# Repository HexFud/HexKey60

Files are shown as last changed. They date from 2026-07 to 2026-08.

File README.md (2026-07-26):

## HexKey60

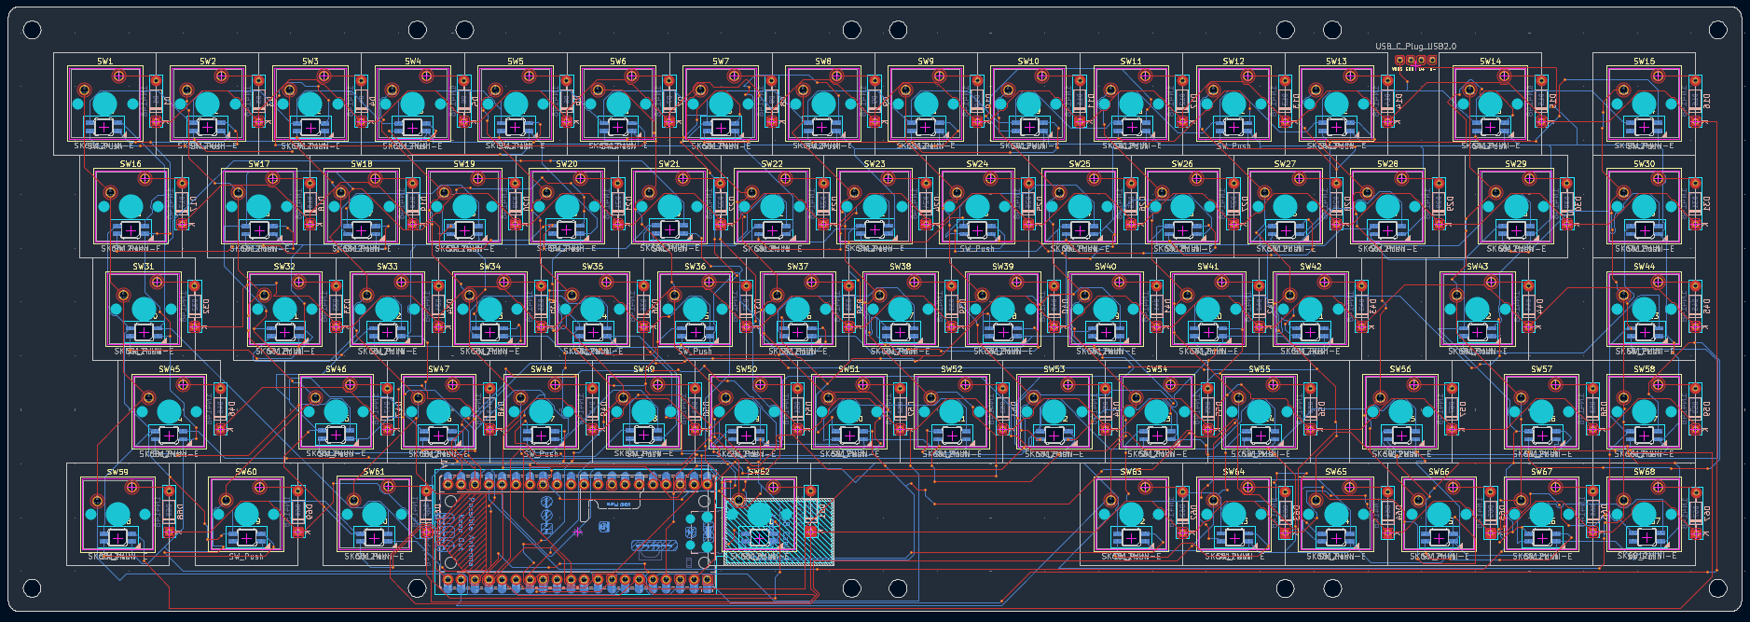
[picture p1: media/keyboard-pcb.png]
HexKey60


Just a custom mechanical keyboard project designed by me

## Specs

- **Layout:** 68 keys, 15 columns x 5 rows matrix, ANSI 65% (up arrow between right Shift and Delete, left/down/right arrows on the bottom row, Fn next to AltGr)
- **Microcontroller:** Raspberry Pi Pico (RP2040), mounted under the spacebar
- **LEDs:** SK6812MINI-E, one per key, same color across the whole board
- **Matrix diodes:** 1N4148, one per switch
- **USB:** routed from the microcontroller (under the spacebar) up to the connector at the top of the case via a Treedix USB-C breakout

## Why the Pico and not something smaller

Originally I was going for something more compact (Orpheus Pico, then XIAO RP2040, then RP2040-Zero) because the standard Pico seemed too bulky to fit between the switches. That problem went away once I moved the microcontroller under the spacebar, where there's way more free space, at that point the regular Pico made more sense, i had space to place it and it has enough pins to fit evry component.

## Matrix

- Rows: GPIO0-GPIO4
- Columns: GPIO5-GPIO19
- Every switch has its own diode to prevent ghosting

## LEDs

Driven via PIO on GPIO21.

LED power comes straight from VBUS (5V), not from the Pico's 3.3V regulator, so the current spikes from 68 LEDs at once don't stress it. Max brightness needs to stay capped in firmware.

## USB

The Pico sits under the spacebar, away from the case edge where the connector needs to come out. D+/D- are hand-wired to test points TP2/TP3 on the back of the Pico (not routed through the PCB), going to a Treedix USB-C breakout mounted in the case. CC1/CC2 on the breakout already have pull-down resistors built in, so they're left unconnected.

## Plate

The plate and the case are fully 3d printed

## Firmware

Live control from a PC over Raw HID (`tastiera68_controller.py`, requires `pip install hidapi`):
- change LED color on the fly (persistent, saved to the Pico's emulated EEPROM)
- remap any key without reflashing (also persistent, saved to a dedicated EEPROM area)

## Building the firmware

### 1. Get QMK

If you don't already have a QMK checkout:

```
git clone https://github.com/qmk/qmk_firmware.git
cd qmk_firmware
```

Follow QMK's own setup guide once (https://docs.qmk.fm/#/newbs_getting_started)
to install the build environment (Python, the ARM toolchain, etc.) if you
haven't done that before — it's a one-time setup per PC.

### 2. Drop this keyboard into the QMK tree

Copy the whole `HexKey60` folder into `qmk_firmware/keyboards/`, so you end
up with:

```
qmk_firmware/
  keyboards/
    HexKey60/
      info.json
      keymaps/
        default/
          keymap.c
          rules.mk
```

### 3. Compile

From the `qmk_firmware` root:

```
qmk compile -kb HexKey60 -km default
```

If everything is set up correctly this produces a file called something
like `HexKey60_default.uf2` in the `qmk_firmware` root folder.

If the build fails on the EEPROM driver lines in `rules.mk`
(`EEPROM_DRIVER` / `WEAR_LEVELING_DRIVER`), check QMK's current docs for the
exact driver name used for RP2040 in your checkout's version — the name has
changed between QMK releases.

### 4. Put the Pico into bootloader mode

The RP2040 shows up as a USB mass-storage drive (`RPI-RP2`) when it's ready
to receive new firmware:

1. Unplug the keyboard.
2. Hold down the **BOOTSEL** button on the Pico (the small white button on
   the board itself).
3. While still holding it, plug the USB cable back in.
4. Let go of the button — a drive called `RPI-RP2` should appear on your
   computer, the same way a USB flash drive would.

### 5. Flash

Just drag and drop the `.uf2` file you built in step 3 onto the `RPI-RP2`
drive. The Pico reboots on its own as soon as the copy finishes, and the
keyboard should now be running your firmware.

If `qmk flash` is set up on your system instead, this also works and does
the copy for you:

```
qmk flash -kb HexKey60 -km default
```

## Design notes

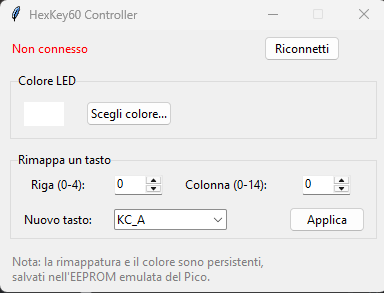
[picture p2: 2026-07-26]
media/firmware.png

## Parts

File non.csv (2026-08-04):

Item | Quantity | Notes | Estimated Price (EUR)
Akko CS 36gf Tactile Keyboard Switches - Lavender Purple, Plate Mounted, Compatible for MX Mechanical Keyboard | 1 | Matrix switches (usually sold in boxes of 45, a 65/75% layout requires 2 boxes) | 35.00
1N4148 Diodes | 68 | One per switch, matrix diode | 3.00
Orpheus Pico | 1 | Microcontroller | 7.50
EG Everglide Panda Stabilizer Gold Plated Plate Mounted Black White Stabilizer (EG Panda for 104) | 1 | Stabilizers for long keys | 20.00
SK6812 MINI-E LEDs | 68 | One per key, wired as 7 parallel groups on GPIO21 (single static color) | 12.50
PCB (see the production folder) | 1 | Custom printed circuit board | 25.00
AKKO Black & Gold ISO Nordic Keycap Set (76-Key) | 1 | Keycap set | 55.00
Adafruit USB Type C Breakout Board - Downstream Connection | 1 | USB-C connector breakout | 6.00
Case | 1 | 3D Printed | 20.00
Plate | 1 | 3D Printed | 7.50

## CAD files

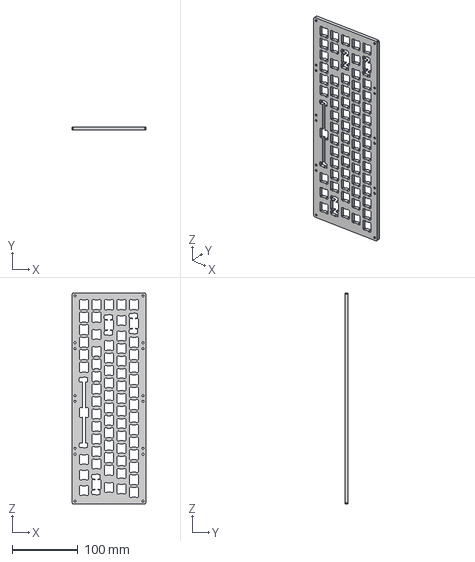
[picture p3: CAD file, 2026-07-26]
CAD/plate.step
112.3 x 5.00 x 321.8 mm

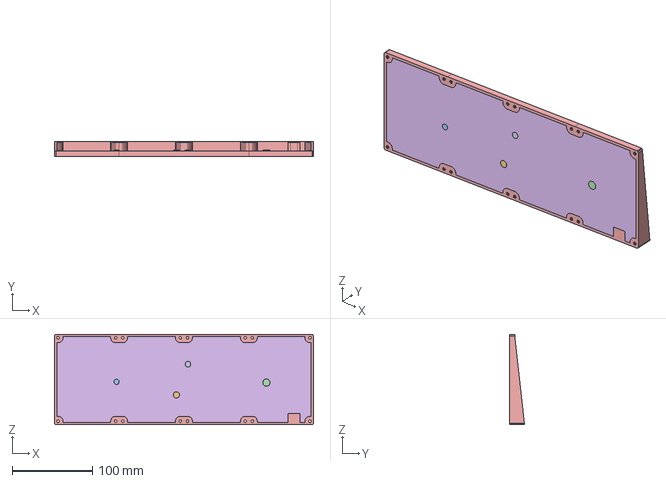
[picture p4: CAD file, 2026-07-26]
CAD/case.step
321.8 x 18.8 x 112.3 mm

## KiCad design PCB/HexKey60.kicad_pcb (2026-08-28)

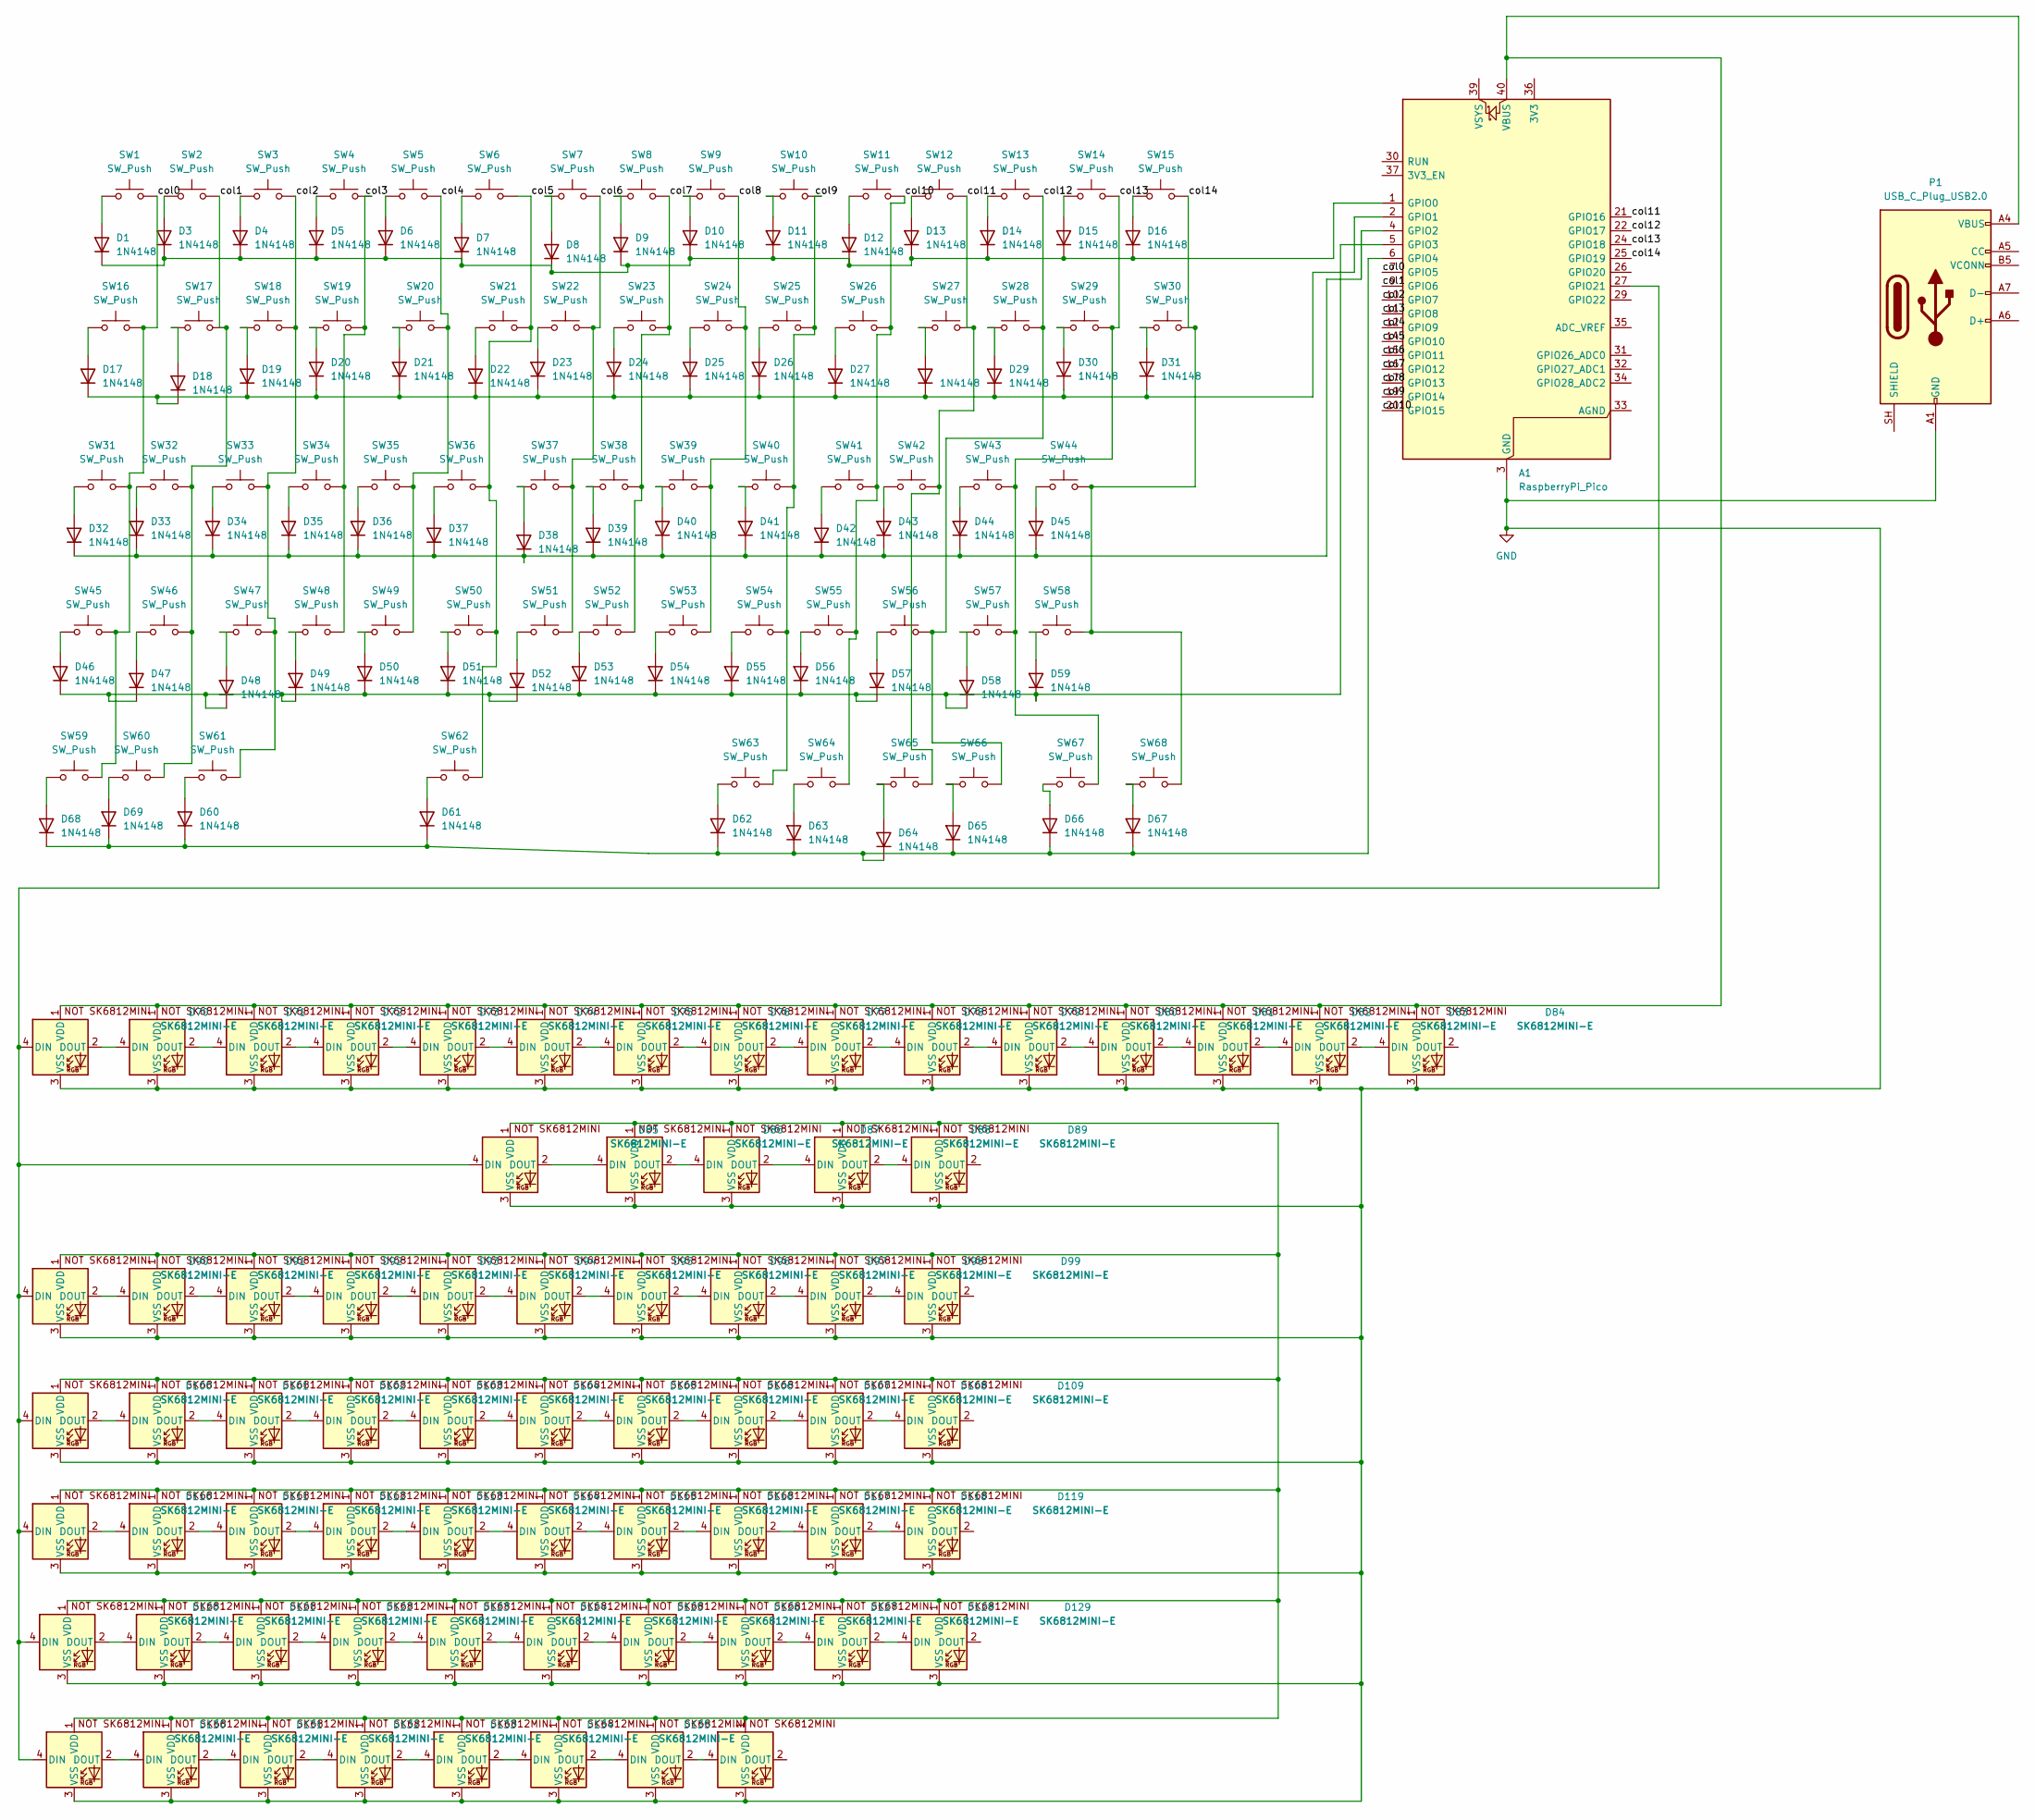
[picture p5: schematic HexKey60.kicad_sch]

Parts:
A1: RaspberryPi_Pico; RaspberryPi_Pico_Common_Unspecified
D1, D3, D4, D5, D6, D7, D8, D9, D10, D11, D12, D13, D14, D15, D16, D17, D18, D19, D20, D21, D22, D23, D24, D25, D26, D27, D28, D29, D30, D31, D32, D33, D34, D35, D36, D37, D38, D39, D40, D41, D42, D43, D44, D45, D46, D47, D48, D49, D50, D51, D52, D53, D54, D55, D56, D57, D58, D59, D60, D61, D62, D63, D64, D65, D66, D67, D68, D69: 1N4148; D_DO-35_SOD27_P7.62mm_Horizontal
D70, D71, D72, D73, D74, D75, D76, D77, D78, D79, D80, D81, D82, D83, D84, D85, D86, D87, D88, D89, D90, D91, D92, D93, D94, D95, D96, D97, D98, D99, D100, D101, D102, D103, D104, D105, D106, D107, D108, D109, D110, D111, D112, D113, D114, D115, D116, D117, D118, D119, D120, D121, D122, D123, D124, D125, D126, D127, D128, D129, D130, D131, D132, D133, D134, D135, D136, D137: SK6812MINI-E; SK6812MINI-E_fixed
P1: USB_C_Plug_USB2.0; usbc board
SW1, SW2, SW3, SW4, SW5, SW6, SW7, SW8, SW9, SW10, SW11, SW12, SW13, SW14, SW15, SW16, SW17, SW18, SW19, SW20, SW21, SW22, SW23, SW24, SW25, SW26, SW27, SW28, SW29, SW30, SW31, SW32, SW33, SW34, SW35, SW36, SW37, SW38, SW39, SW40, SW41, SW42, SW43, SW44, SW45, SW46, SW47, SW48, SW49, SW50, SW51, SW52, SW53, SW54, SW55, SW56, SW57, SW58, SW59, SW60, SW61, SW62, SW63, SW64, SW65, SW66, SW67, SW68: SW_Push; SW_Cherry_MX_1.00u_PCB

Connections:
/<NO NET>: A1.7 (GPIO5), SW1.2, SW16.2, SW31.2, SW45.2, SW59.2
/col1: A1.9 (GPIO6), SW2.2, SW17.2, SW32.2, SW46.2, SW60.2
/col2: A1.10 (GPIO7), SW3.2, SW18.2, SW33.2, SW47.2, SW61.2
/col3: A1.11 (GPIO8), SW4.2, SW19.2, SW34.2, SW48.2
/col4: A1.12 (GPIO9), SW5.2, SW20.2, SW35.2, SW49.2
/col5: A1.14 (GPIO10), SW6.2, SW21.2, SW36.2, SW50.2, SW62.2
/col6: A1.15 (GPIO11), SW7.2, SW22.2, SW37.2, SW51.2
/col7: A1.16 (GPIO12), SW8.2, SW23.2, SW38.2, SW52.2
/col8: A1.17 (GPIO13), SW9.2, SW24.2, SW39.2, SW53.2
/col9: A1.19 (GPIO14), SW10.2, SW25.2, SW40.2, SW54.2, SW63.2
/col10: A1.20 (GPIO15), SW11.2, SW26.2, SW41.2, SW55.2, SW64.2
/col11: A1.21 (GPIO16), SW12.2, SW27.2, SW42.2, SW65.2
/col12: A1.22 (GPIO17), SW13.2, SW28.2, SW56.2, SW66.2
/col13: A1.24 (GPIO18), SW14.2, SW29.2, SW43.2, SW57.2, SW67.2
/col14: A1.25 (GPIO19), SW15.2, SW30.2, SW44.2, SW58.2, SW68.2
GND: A1.3 (GND), A1.8 (GND), A1.13 (GND), A1.18 (GND), A1.23 (GND), A1.28 (GND), A1.38 (GND), D70.3 (VSS), D71.3 (VSS), D72.3 (VSS), D73.3 (VSS), D74.3 (VSS), D75.3 (VSS), D76.3 (VSS), D77.3 (VSS), D78.3 (VSS), D79.3 (VSS), D80.3 (VSS), D81.3 (VSS), D82.3 (VSS), D83.3 (VSS), D84.3 (VSS), D85.3 (VSS), D86.3 (VSS), D87.3 (VSS), D88.3 (VSS), D89.3 (VSS), D90.3 (VSS), D91.3 (VSS), D92.3 (VSS), D93.3 (VSS), D94.3 (VSS), D95.3 (VSS), D96.3 (VSS), D97.3 (VSS), D98.3 (VSS), D99.3 (VSS), D100.3 (VSS), D101.3 (VSS), D102.3 (VSS), D103.3 (VSS), D104.3 (VSS), D105.3 (VSS), D106.3 (VSS), D107.3 (VSS), D108.3 (VSS), D109.3 (VSS), D110.3 (VSS), D111.3 (VSS), D112.3 (VSS), D113.3 (VSS), D114.3 (VSS), D115.3 (VSS), D116.3 (VSS), D117.3 (VSS), D118.3 (VSS), D119.3 (VSS), D120.3 (VSS), D121.3 (VSS), D122.3 (VSS), D123.3 (VSS), D124.3 (VSS), D125.3 (VSS), D126.3 (VSS), D127.3 (VSS), D128.3 (VSS), D129.3 (VSS), D130.3 (VSS), D131.3 (VSS), D132.3 (VSS), D133.3 (VSS), D134.3 (VSS), D135.3 (VSS), D136.3 (VSS), D137.3 (VSS), P1.A1 (GND), P1.A12 (GND), P1.B1 (GND), P1.B12 (GND)
unnamed: A1.1 (GPIO0), D1.1 (K), D3.1 (K), D4.1 (K), D5.1 (K), D6.1 (K), D7.1 (K), D8.1 (K), D9.1 (K), D10.1 (K), D11.1 (K), D12.1 (K), D13.1 (K), D14.1 (K), D15.1 (K), D16.1 (K)
unnamed: A1.2 (GPIO1), D17.1 (K), D18.1 (K), D19.1 (K), D20.1 (K), D21.1 (K), D22.1 (K), D23.1 (K), D24.1 (K), D25.1 (K), D26.1 (K), D27.1 (K), D28.1 (K), D29.1 (K), D30.1 (K), D31.1 (K)
unnamed: A1.4 (GPIO2), D32.1 (K), D33.1 (K), D34.1 (K), D35.1 (K), D36.1 (K), D37.1 (K), D38.1 (K), D39.1 (K), D40.1 (K), D41.1 (K), D42.1 (K), D43.1 (K), D44.1 (K), D45.1 (K)
unnamed: A1.5 (GPIO3), D46.1 (K), D47.1 (K), D48.1 (K), D49.1 (K), D50.1 (K), D51.1 (K), D52.1 (K), D53.1 (K), D54.1 (K), D55.1 (K), D56.1 (K), D57.1 (K), D58.1 (K), D59.1 (K)
unnamed: A1.6 (GPIO4), D60.1 (K), D61.1 (K), D62.1 (K), D63.1 (K), D64.1 (K), D65.1 (K), D66.1 (K), D67.1 (K), D68.1 (K), D69.1 (K)
unnamed: A1.27 (GPIO21), D70.4 (DIN), D85.4 (DIN), D90.4 (DIN), D100.4 (DIN), D110.4 (DIN), D120.4 (DIN), D130.4 (DIN)
unnamed: A1.40 (VBUS), D70.1 (VDD), D71.1 (VDD), D72.1 (VDD), D73.1 (VDD), D74.1 (VDD), D75.1 (VDD), D76.1 (VDD), D77.1 (VDD), D78.1 (VDD), D79.1 (VDD), D80.1 (VDD), D81.1 (VDD), D82.1 (VDD), D83.1 (VDD), D84.1 (VDD), P1.A4 (VBUS), P1.A9 (VBUS), P1.B4 (VBUS), P1.B9 (VBUS)
unnamed: D1.2 (A), SW1.1
unnamed: D3.2 (A), SW2.1
unnamed: D4.2 (A), SW3.1
unnamed: D5.2 (A), SW4.1
unnamed: D6.2 (A), SW5.1
unnamed: D7.2 (A), SW6.1
unnamed: D8.2 (A), SW7.1
unnamed: D9.2 (A), SW8.1
unnamed: D10.2 (A), SW9.1
unnamed: D11.2 (A), SW10.1
unnamed: D12.2 (A), SW11.1
unnamed: D13.2 (A), SW12.1
unnamed: D14.2 (A), SW13.1
unnamed: D15.2 (A), SW14.1
unnamed: D16.2 (A), SW15.1
unnamed: D17.2 (A), SW16.1
unnamed: D18.2 (A), SW17.1
unnamed: D19.2 (A), SW18.1
unnamed: D20.2 (A), SW19.1
unnamed: D21.2 (A), SW20.1
unnamed: D22.2 (A), SW21.1
unnamed: D23.2 (A), SW22.1
unnamed: D24.2 (A), SW23.1
unnamed: D25.2 (A), SW24.1
unnamed: D26.2 (A), SW25.1
unnamed: D27.2 (A), SW26.1
unnamed: D28.2 (A), SW27.1
unnamed: D29.2 (A), SW28.1
unnamed: D30.2 (A), SW29.1
unnamed: D31.2 (A), SW30.1
unnamed: D32.2 (A), SW31.1
unnamed: D33.2 (A), SW32.1
unnamed: D34.2 (A), SW33.1
unnamed: D35.2 (A), SW34.1
unnamed: D36.2 (A), SW35.1
unnamed: D37.2 (A), SW36.1
unnamed: D38.2 (A), SW37.1
unnamed: D39.2 (A), SW38.1
unnamed: D40.2 (A), SW39.1
unnamed: D41.2 (A), SW40.1
unnamed: D42.2 (A), SW41.1
unnamed: D43.2 (A), SW42.1
unnamed: D44.2 (A), SW43.1
unnamed: D45.2 (A), SW44.1
unnamed: D46.2 (A), SW45.1
unnamed: D47.2 (A), SW46.1
unnamed: D48.2 (A), SW47.1
unnamed: D49.2 (A), SW48.1
unnamed: D50.2 (A), SW49.1
unnamed: D51.2 (A), SW50.1
unnamed: D52.2 (A), SW51.1
unnamed: D53.2 (A), SW52.1
unnamed: D54.2 (A), SW53.1
unnamed: D55.2 (A), SW54.1
unnamed: D56.2 (A), SW55.1
unnamed: D57.2 (A), SW56.1
unnamed: D58.2 (A), SW57.1
unnamed: D59.2 (A), SW58.1
unnamed: D60.2 (A), SW61.1
unnamed: D61.2 (A), SW62.1
unnamed: D62.2 (A), SW63.1
unnamed: D63.2 (A), SW64.1
unnamed: D64.2 (A), SW65.1
unnamed: D65.2 (A), SW66.1
unnamed: D66.2 (A), SW67.1
unnamed: D67.2 (A), SW68.1
unnamed: D68.2 (A), SW59.1
unnamed: D69.2 (A), SW60.1
unnamed: D70.2 (DOUT), D71.4 (DIN)
unnamed: D71.2 (DOUT), D72.4 (DIN)
unnamed: D72.2 (DOUT), D73.4 (DIN)
unnamed: D73.2 (DOUT), D74.4 (DIN)
unnamed: D74.2 (DOUT), D75.4 (DIN)
unnamed: D75.2 (DOUT), D76.4 (DIN)
unnamed: D76.2 (DOUT), D77.4 (DIN)
unnamed: D77.2 (DOUT), D78.4 (DIN)
unnamed: D78.2 (DOUT), D79.4 (DIN)
unnamed: D79.2 (DOUT), D80.4 (DIN)
unnamed: D80.2 (DOUT), D81.4 (DIN)
unnamed: D81.2 (DOUT), D82.4 (DIN)
unnamed: D82.2 (DOUT), D83.4 (DIN)
unnamed: D83.2 (DOUT), D84.4 (DIN)
unnamed: D85.2 (DOUT), D86.4 (DIN)
unnamed: D86.2 (DOUT), D87.4 (DIN)
unnamed: D87.2 (DOUT), D88.4 (DIN)
unnamed: D88.2 (DOUT), D89.4 (DIN)
unnamed: D90.2 (DOUT), D91.4 (DIN)
unnamed: D91.2 (DOUT), D92.4 (DIN)
unnamed: D92.2 (DOUT), D93.4 (DIN)
unnamed: D93.2 (DOUT), D94.4 (DIN)
unnamed: D94.2 (DOUT), D95.4 (DIN)
unnamed: D95.2 (DOUT), D96.4 (DIN)
unnamed: D96.2 (DOUT), D97.4 (DIN)
unnamed: D97.2 (DOUT), D98.4 (DIN)
unnamed: D98.2 (DOUT), D99.4 (DIN)
unnamed: D100.2 (DOUT), D101.4 (DIN)
unnamed: D85.1 (VDD), D86.1 (VDD), D87.1 (VDD), D88.1 (VDD), D89.1 (VDD), D90.1 (VDD), D91.1 (VDD), D92.1 (VDD), D93.1 (VDD), D94.1 (VDD), D95.1 (VDD), D96.1 (VDD), D97.1 (VDD), D98.1 (VDD), D99.1 (VDD), D100.1 (VDD), D101.1 (VDD), D102.1 (VDD), D103.1 (VDD), D104.1 (VDD), D105.1 (VDD), D106.1 (VDD), D107.1 (VDD), D108.1 (VDD), D109.1 (VDD), D110.1 (VDD), D111.1 (VDD), D112.1 (VDD), D113.1 (VDD), D114.1 (VDD), D115.1 (VDD), D116.1 (VDD), D117.1 (VDD), D118.1 (VDD), D119.1 (VDD), D120.1 (VDD), D121.1 (VDD), D122.1 (VDD), D123.1 (VDD), D124.1 (VDD), D125.1 (VDD), D126.1 (VDD), D127.1 (VDD), D128.1 (VDD), D129.1 (VDD), D130.1 (VDD), D131.1 (VDD), D132.1 (VDD), D133.1 (VDD), D134.1 (VDD), D135.1 (VDD), D136.1 (VDD), D137.1 (VDD)
unnamed: D101.2 (DOUT), D102.4 (DIN)
unnamed: D102.2 (DOUT), D103.4 (DIN)
unnamed: D103.2 (DOUT), D104.4 (DIN)
unnamed: D104.2 (DOUT), D105.4 (DIN)
unnamed: D105.2 (DOUT), D106.4 (DIN)
unnamed: D106.2 (DOUT), D107.4 (DIN)
unnamed: D107.2 (DOUT), D108.4 (DIN)
unnamed: D108.2 (DOUT), D109.4 (DIN)
unnamed: D110.2 (DOUT), D111.4 (DIN)
unnamed: D111.2 (DOUT), D112.4 (DIN)
unnamed: D112.2 (DOUT), D113.4 (DIN)
unnamed: D113.2 (DOUT), D114.4 (DIN)
unnamed: D114.2 (DOUT), D115.4 (DIN)
unnamed: D115.2 (DOUT), D116.4 (DIN)
unnamed: D116.2 (DOUT), D117.4 (DIN)
unnamed: D117.2 (DOUT), D118.4 (DIN)
unnamed: D118.2 (DOUT), D119.4 (DIN)
unnamed: D120.2 (DOUT), D121.4 (DIN)
unnamed: D121.2 (DOUT), D122.4 (DIN)
unnamed: D122.2 (DOUT), D123.4 (DIN)
unnamed: D123.2 (DOUT), D124.4 (DIN)
unnamed: D124.2 (DOUT), D125.4 (DIN)
unnamed: D125.2 (DOUT), D126.4 (DIN)
unnamed: D126.2 (DOUT), D127.4 (DIN)
unnamed: D127.2 (DOUT), D128.4 (DIN)
unnamed: D128.2 (DOUT), D129.4 (DIN)
unnamed: D130.2 (DOUT), D131.4 (DIN)
unnamed: D131.2 (DOUT), D132.4 (DIN)
unnamed: D132.2 (DOUT), D133.4 (DIN)
unnamed: D133.2 (DOUT), D134.4 (DIN)
unnamed: D134.2 (DOUT), D135.4 (DIN)
unnamed: D135.2 (DOUT), D136.4 (DIN)
unnamed: D136.2 (DOUT), D137.4 (DIN)

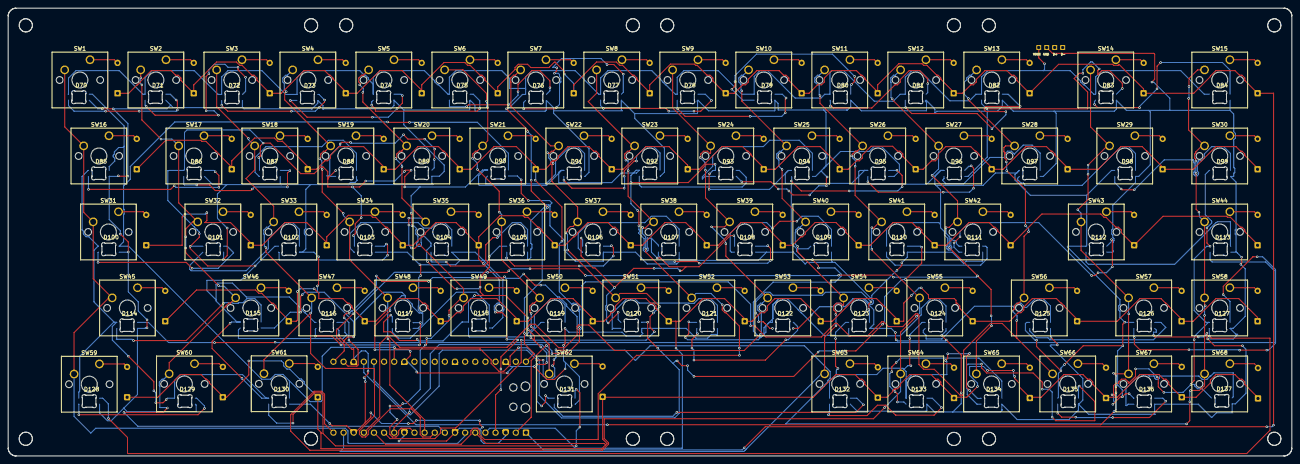
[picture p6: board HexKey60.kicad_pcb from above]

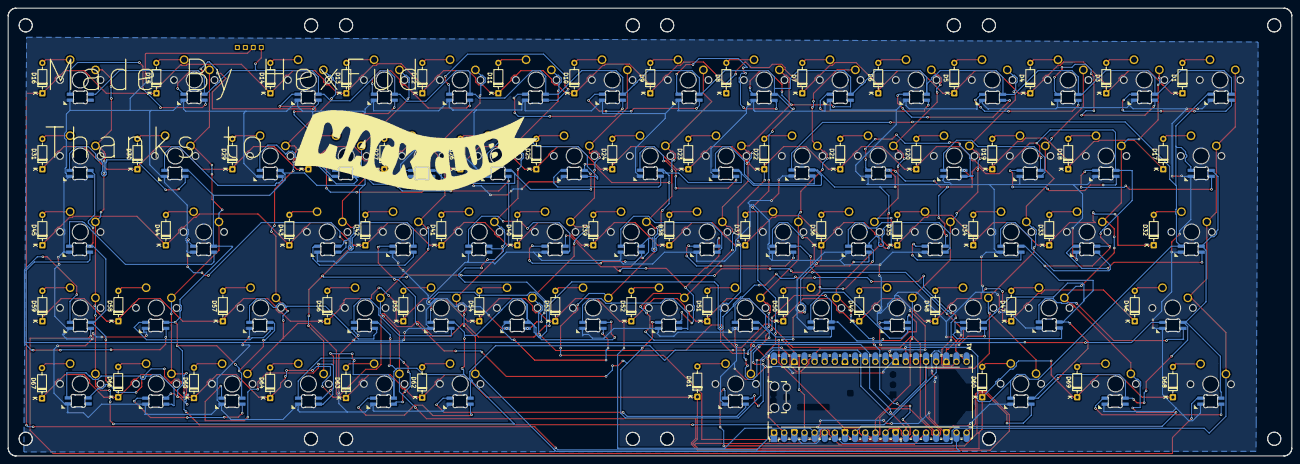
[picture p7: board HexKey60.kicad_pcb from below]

Board: 2 copper layers, 321.8 x 112.3 mm, 206 parts (69 on the bottom side), 153 nets.

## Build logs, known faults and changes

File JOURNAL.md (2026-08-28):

This is my journey about how i built my keybaord

## Day 1 — *~3 hours*

Finally understood how a matrix work and connecting the first switches. Took a while to wrap my head around rows/columns and why you need diodes to avoid ghosting, but once it clicked the wiring made a lot more sense.

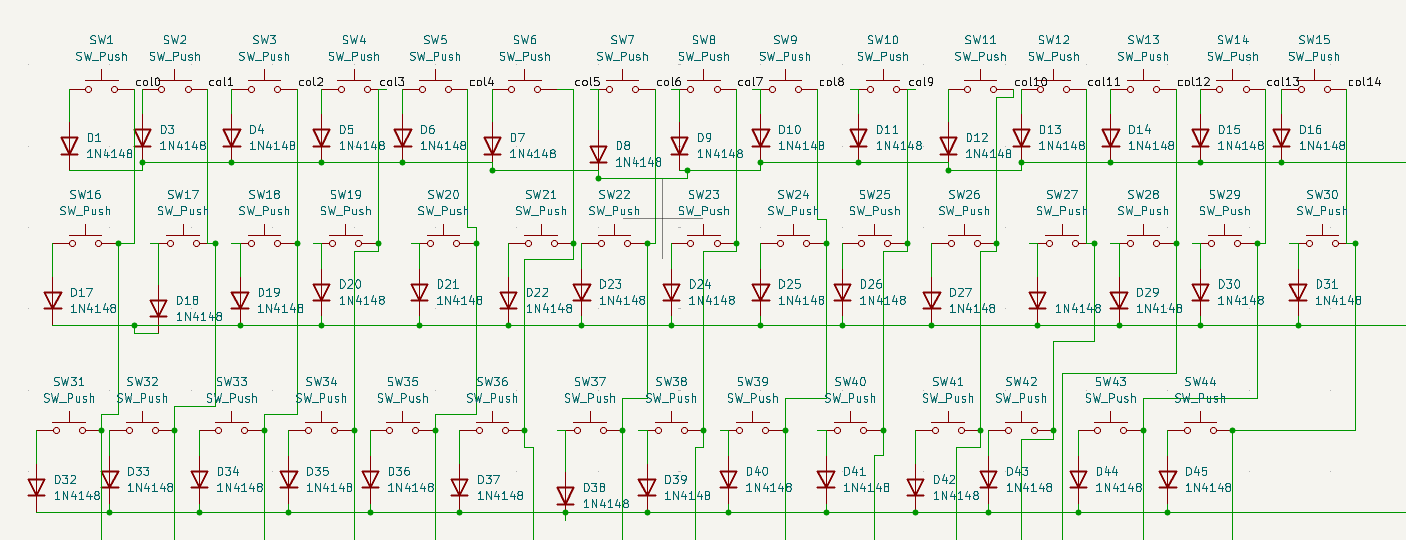
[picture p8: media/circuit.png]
Circuit Matrix


Yes! After so many hours of work i finished the schematic but i am still not sure what microcontroller i need to use, i'll figure out later. Spent most of the time double checking pin assignments so I wouldn't have to redo the routing later.

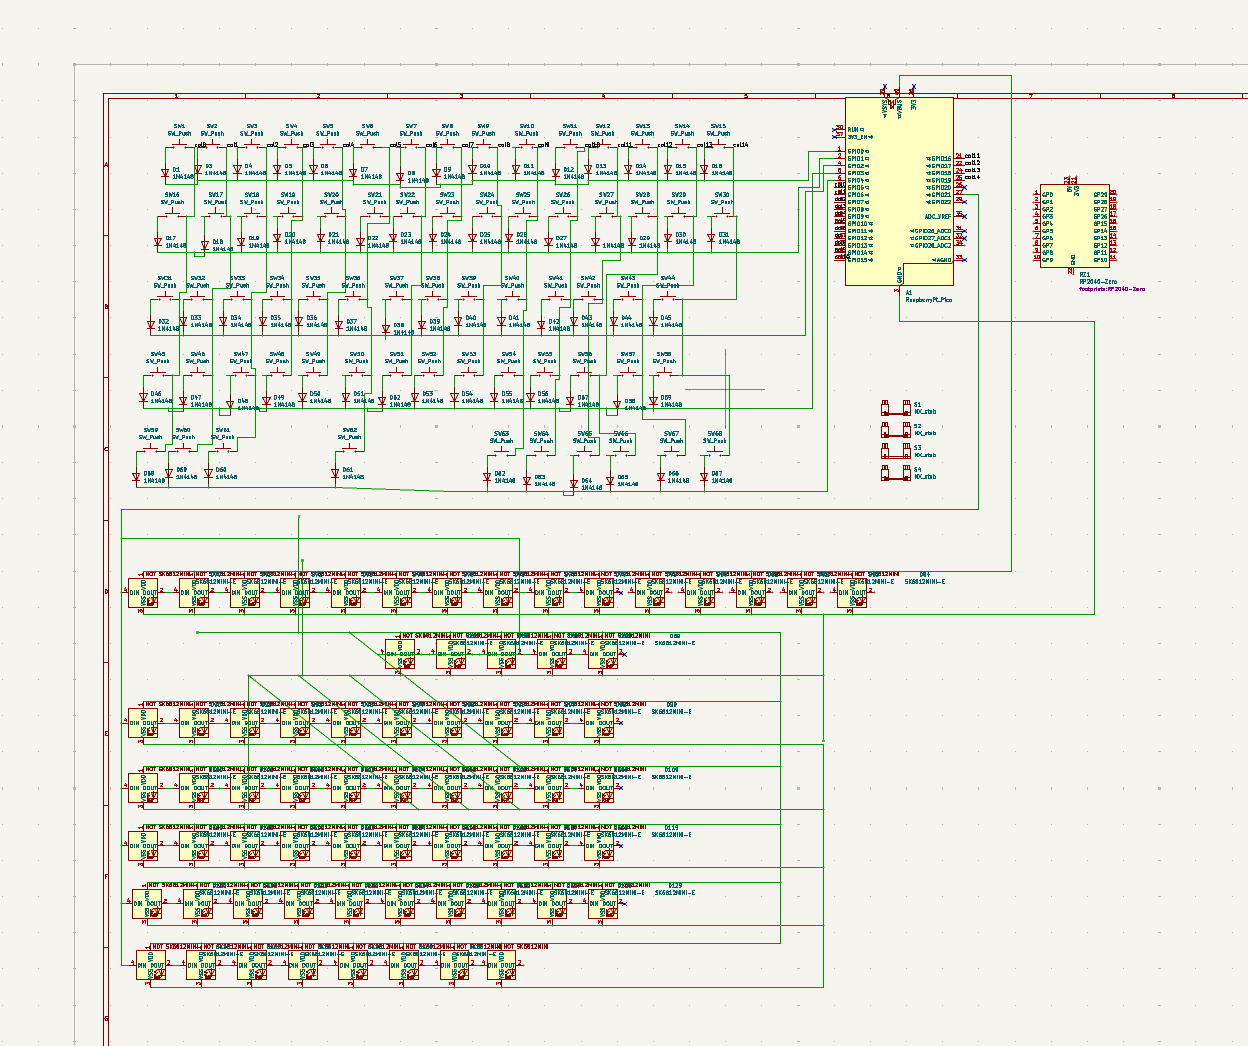
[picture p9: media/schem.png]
Circuit


## Day 2 — *~2.5 hours*

My attempt to place all the keys an other component was succesful, now it comes the wiring. Getting the footprints lined up on the 15x5 matrix took some trial and error, especially spacing them evenly for the non-standard rows.

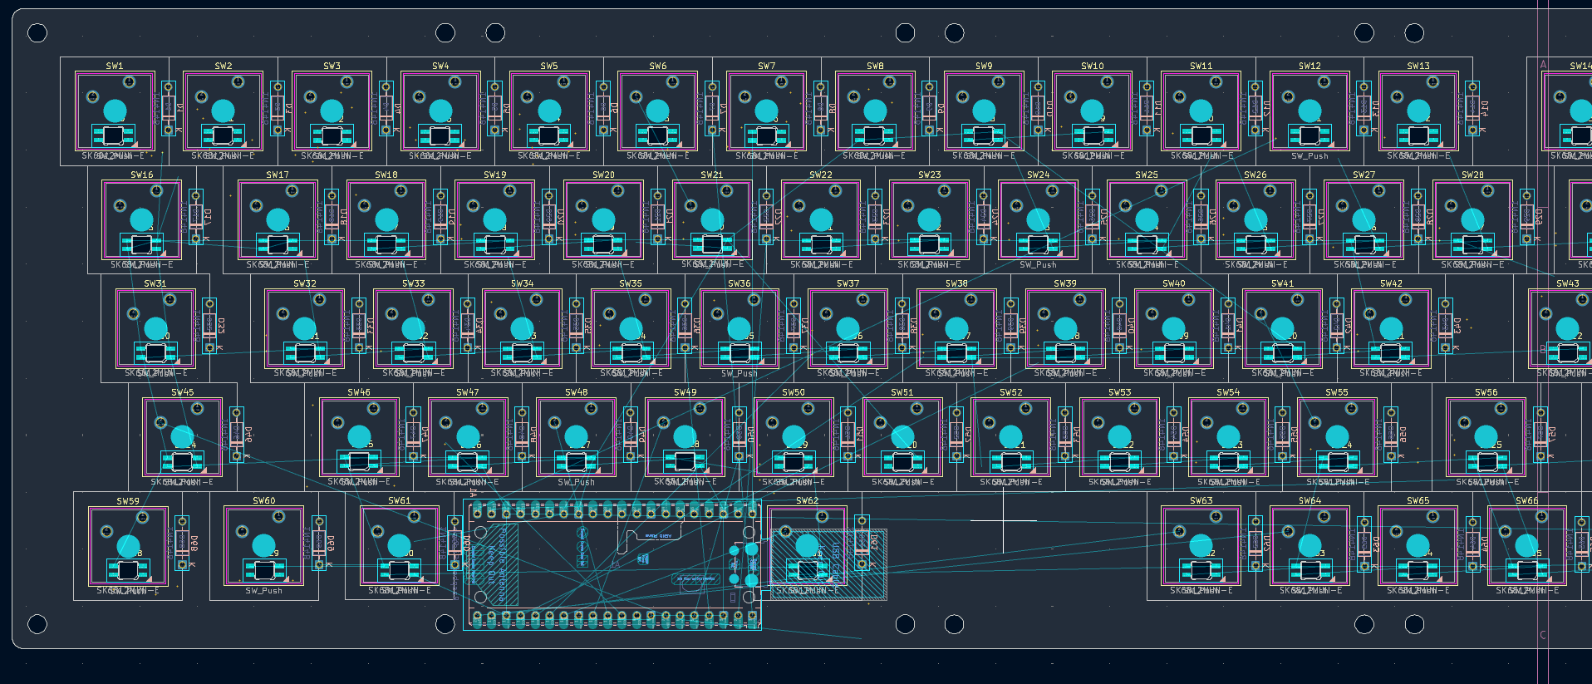
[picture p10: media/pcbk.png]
PCB


## Day 3 — *~5 hours*

PCB almost finished! It took a lot of time because the connections are A LOT. Now there are only few of them i still need to connect. This was by far the most tedious part of the whole build — routing 68 switches plus diodes and LEDs on a single board meant constantly rerouting traces to avoid overlaps.

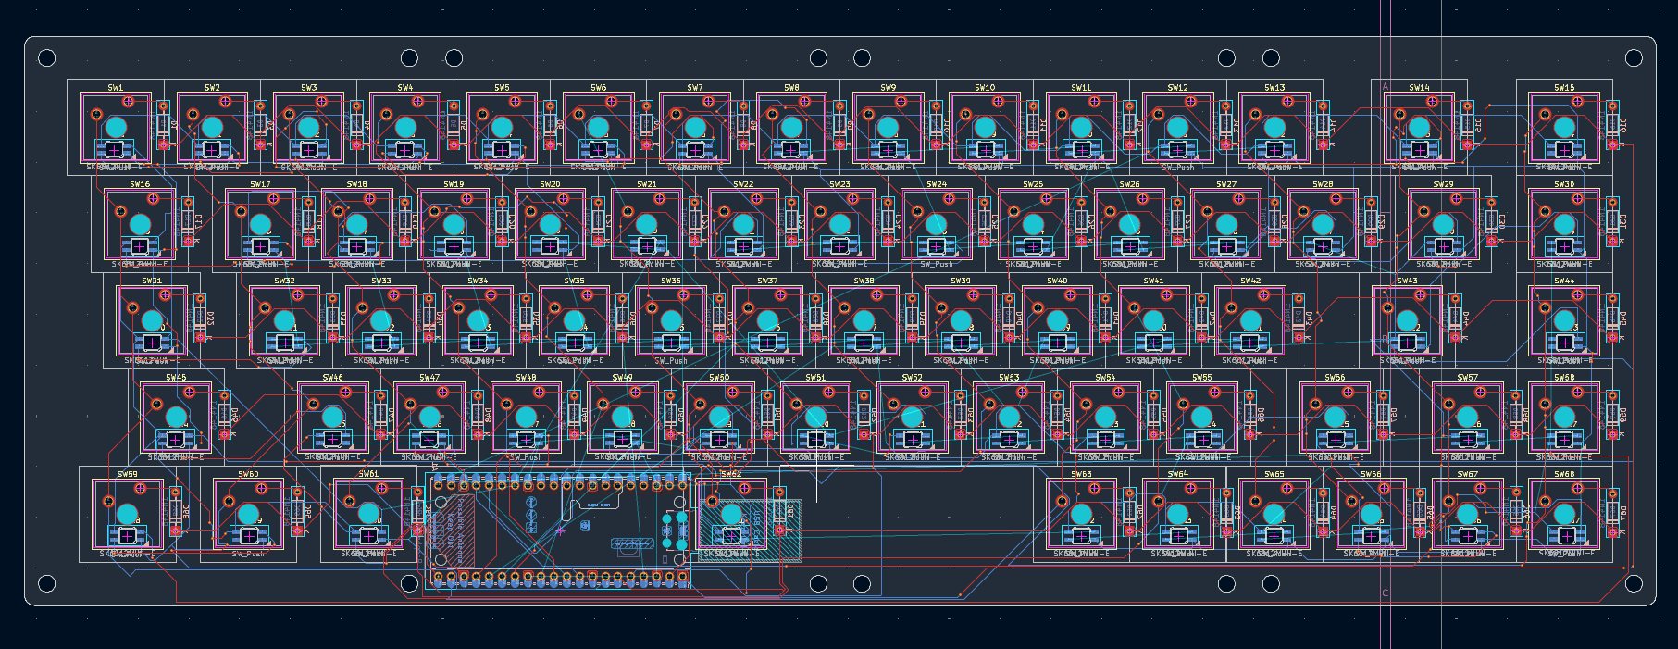
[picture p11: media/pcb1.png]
PCB almost finished


PCB Finalyy finished! Now i only need to tidy the connections and check the DRC. If it comes OK I can finally commit the diagram and PCB! Ran the design rule check a few times and fixed a handful of clearance warnings before it came back clean.

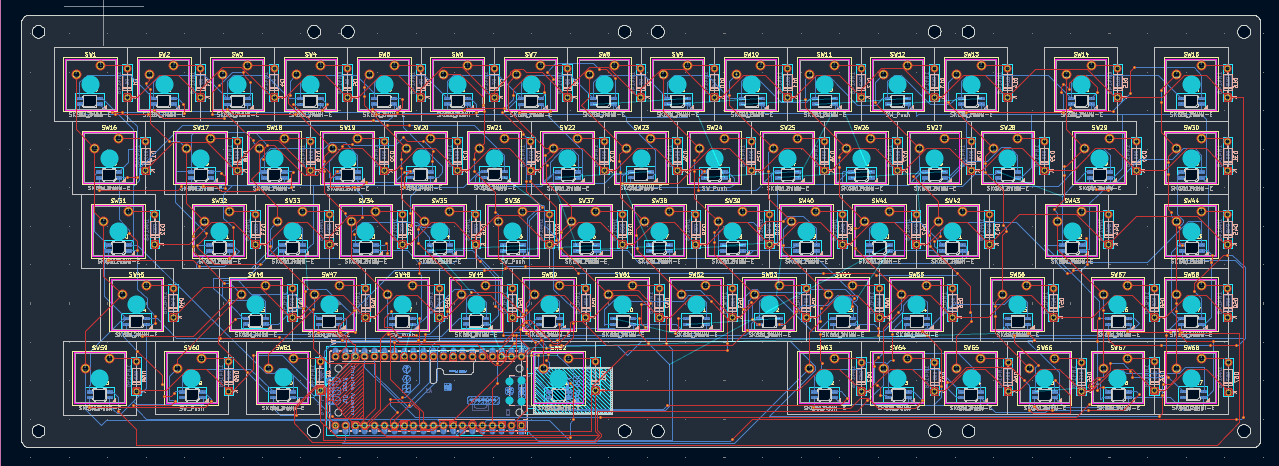
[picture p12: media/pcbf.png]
PCB finished


## Day 4 — *~2 hours*

PCB officially uploaded. Now it comes the case design. Nice to close that chapter and switch to something more physical for a change.

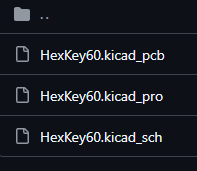
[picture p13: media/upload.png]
File uploaded


Started designign the plate, than it comes the case! Sketched out rough dimensions first to make sure the plate would actually match the PCB mounting holes.

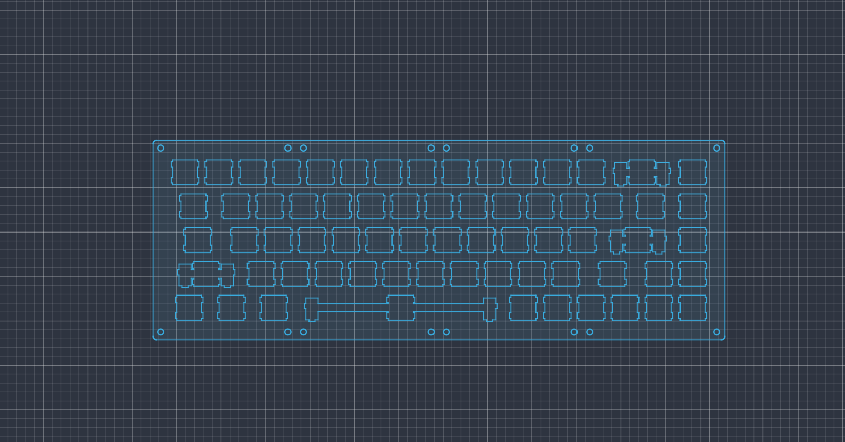
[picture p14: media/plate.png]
Plate


## Day 5 — *~3 hours*

Update:
I ran into a problem, i just realized that it isn't possible to connect the usb to the keybaord because the microcontroller is sitting right under the spacebar. A possible solution is to have a usb female-female inside the case to re-route that port to a nicer spot (probably in the front of the case)

Solution:
I searched up on the internet and i found this board https://www.adafruit.com/product/4090?hl=en-US&utm_source=chatgpt.com (Adafruit USB Type C Breakout Board) so my plan is to screw this into the case and then connect it into the PCB. Soon after i discovered that were 0 footprints about this board so i decided to create my own, with the basic pins with simple thru-hole and later I will use some jumper wires to connect it so i have more flexibility on where to put this board. Building the footprint from scratch meant carefully measuring the hole spacing off the product photos since no datasheet drawing was available.

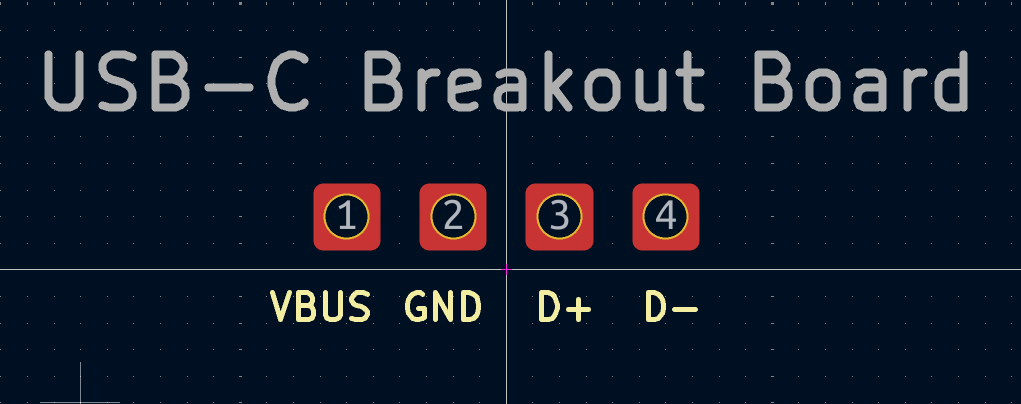
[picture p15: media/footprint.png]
My footprint


## Day 6 — *~3 hours*

Big update on the project. 
To make the USB breakout board work, I need to manually solder the micro-USB pins straight onto the board. There won't be any traces for D+ and D- on the PCB because those pins on the microcontroller are hidden right under the USB port and aren't visible in the schematic.
In the meantime, I've also worked on the case and designed the bottom part with some room for the USB cables, and added a little plate under the USB-C breakout board so I can screw it down securely. That part's done, though I had to tweak it a bit because the keys on the PCB weren't lining up right.

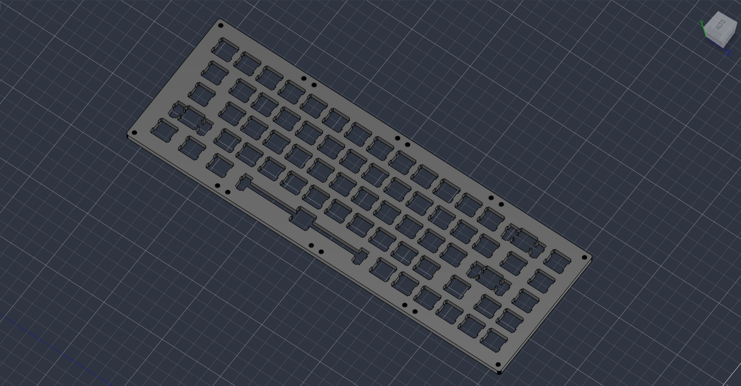
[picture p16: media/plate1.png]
Plate


After a bit of 3D modelling i have made a shape for the bottom of the case, now i need to polish it up and then design the top. Went through a couple of iterations of the walls and standoffs before the fit felt solid.

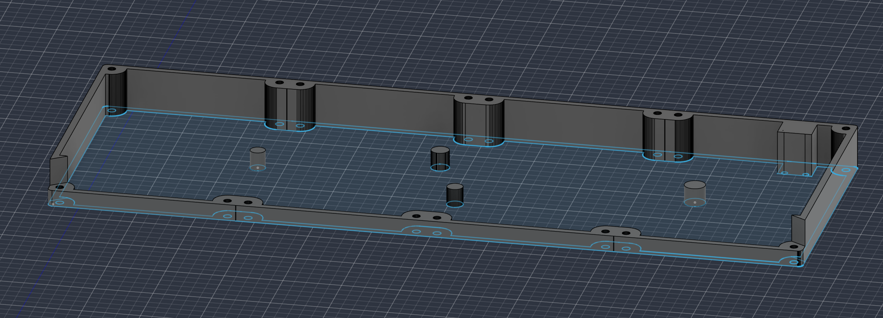
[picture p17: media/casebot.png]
Bottom case


## Day 7 — *~1.5 hours*

Update:
After a bit i came to a conclusion that I don't need to design the top part of the case because I Have designed the pcb and the plate with holes to mount them directly into the bottom part of the case. So I will now code the firmware! Flashing QMK and mapping the layout went pretty smoothly once the hardware was actually done.

## Day 7 — *~6 hours*
Revisioned one last time the project and added some serigraphy, added a GND plan and fixed more than 200+ errors! Now we only need to produce the final product

Final update on this journey, i finished up the project and now i am gonna upload all the files and write a nice README

Time spent on this project: about 26 hours

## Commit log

2026-07-26 Updated BOM
    [bom.xlsx]
2026-08-04 Add initial non.csv file with item details
    [non.csv]
